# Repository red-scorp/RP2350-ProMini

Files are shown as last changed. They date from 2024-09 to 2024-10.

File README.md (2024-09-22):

```
 ######  ######   #####   #####  #######   ###         ######                #     #            
 #     # #     # #     # #     # #        #   #        #     # #####   ####  ##   ## # #    # # 
 #     # #     #       #       # #       #     #       #     # #    # #    # # # # # # ##   # # 
 ######  ######   #####   #####  ######  #     # ##### ######  #    # #    # #  #  # # # #  # # 
 #   #   #       #             #       # #     #       #       #####  #    # #     # # #  # # # 
 #    #  #       #       #     # #     #  #   #        #       #   #  #    # #     # # #   ## # 
 #     # #       #######  #####   #####    ###         #       #    #  ####  #     # # #    # # 
```

# RP2350-ProMini Project

The RP2350-ProMini project aims to create a replacement for the Arduino Pro Mini using the RP2350 MCU.

## RP2350-ProMini Board

The **RP2350-ProMini** board is a 4-layer board designed to accommodate the popular Raspberry Pi RP2350 MCU in the commonly used, but obsolete, Arduino Pro Mini footprint.

This project is a shoot-off from my earlier [RP2040-ProMini](https://github.com/red-scorp/RP2040-ProMini) project, which was designed to accommodate the Raspberry Pi RP2040 MCU in the same footprint.

Preview:

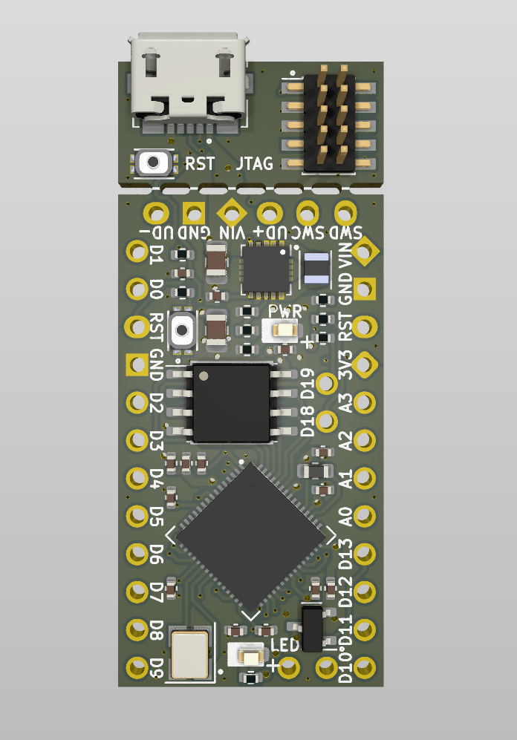
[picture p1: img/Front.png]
RP2350-ProMini Front preview

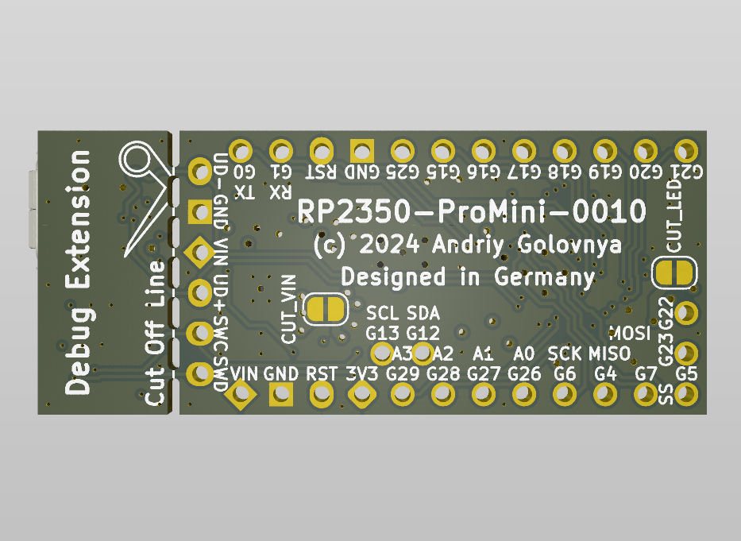
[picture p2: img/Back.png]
RP2350-ProMini Back preview

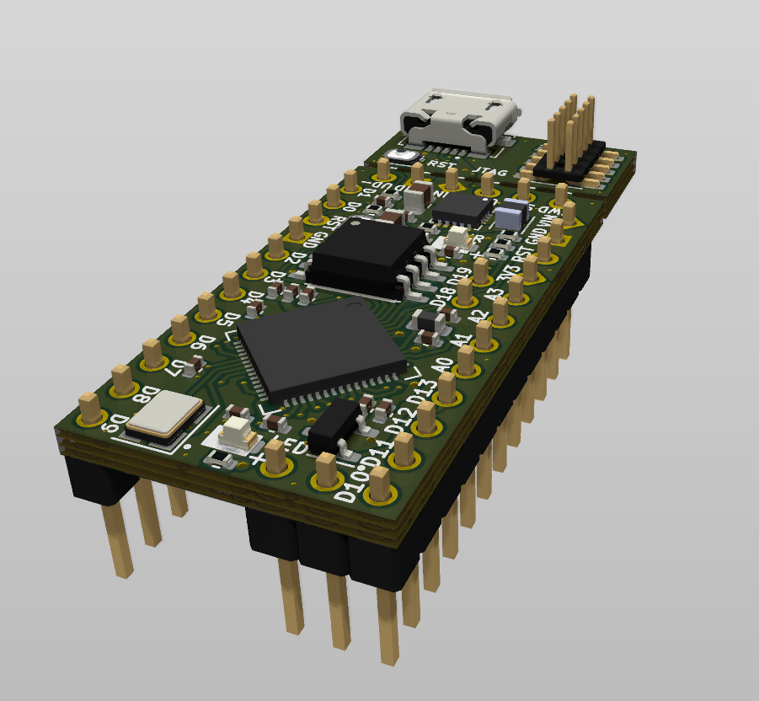
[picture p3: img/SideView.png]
RP2350-ProMini Side View preview


You can view the [Schematics in PDF format](doc/RP2350-ProMini.pdf) for detailed information.

STEP 3D files are available [with pins](doc/RP2350-ProMini-with-pins.step) and [without pins](doc/RP2350-ProMini-board.step).

Features:

- Arduino Pro Mini compatible pinout
- Partially compatible with Arduino Nano RP2040 Connect pinout
- Detachable USB and JTAG extension board with RESET button
- Dual-core Cortex-M33 Raspberry Pi RP2350
- Small footprint suitable for DIY projects
- 21 GPIO pins, including 4 analog inputs
- USB data pins on the side connector
- SWD debugging pins on the side connector
- Buck-Boost converter based 3.3V power supply with input range of 2.5V-12V
- Supports both SOIC and WSON 16MB flash packages
- Flat back side enables use as a sub-assembly
- Two cut points to reduce power consumption of unused components

CAM files, as well as the BOM and CPL files for JLCPCB, are available.

### Board Pinout

Following pinout is used for the board:

| Board Pin | RP2040 Pin | Function | Notes |
| --- | --- | --- | ----- |
| D0 | GPIO1 | UART0 TX | |
| D1 | GPIO0 | UART0 RX | |
| D2 | GPIO25 | | |
| D3 | GPIO15 | | |
| D4 | GPIO16 | | |
| D5 | GPIO17 | | |
| D6 | GPIO18 | | |
| D7 | GPIO19 | | |
| D8 | GPIO20 | | |
| D9 | GPIO21 | | |
| D10 | GPIO5 | SS | |
| D11 | GPIO7 | MOSI | |
| D12 | GPIO4 | MISO | |
| D13 | GPIO6 | SCK | LED |
| D14 A0 | GPIO26 | | |
| D15 A1 | GPIO27 | | |
| D16 A2 | GPIO28 | | |
| D17 A3 | GPIO29 | | |
| D18 | GPIO12 | SDA | |
| D19 | GPIO13 | SCL | |
| D20 | GPIO22 | | |
| D21 | GPIO23 | | |

### Cut Points

There are two cut points on the board to reduce power consumption of unused components.

| Cut Point | Function | Notes |
| --- | --- | ----- |
| CUT_VIN | Separates VIN-to-3V3 power supply with power LED from the rest of the board | This cut point is useful if you want to power the board from 3V3 pin instead of VIN pin. |
| CUT_LED | Separates LED on pin D13 from the rest of the board | This cut point is useful if you want to reduce power consumption of the board. |

## Version History

### v1.0b1 - xx.xx.2024

v1.0b1 board preview

Initial release for testing purposes.

## Links

- [Raspberry Pi RP2350 information page](https://www.raspberrypi.com/documentation/microcontrollers/silicon.html#rp2350).
- [Arduino Pro Mini information page](https://docs.arduino.cc/retired/boards/arduino-pro-mini).
- [Arduino Nano RP2040 Connect page](https://docs.arduino.cc/hardware/nano-rp2040-connect).
- [Arduino SDK for RP2040/RP2350 board](https://github.com/earlephilhower/arduino-pico).

## How to Help

Your contributions as code, resources, or finances are welcome! Please contact me directly via email at andriy.golovnya@gmail.com or through my [GitHub profile](https://github.com/red-scorp).

If you'd like to make a financial contribution, you can donate via [PayPal](http://paypal.me/redscorp) or [Ko-Fi](http://ko-fi.com/redscorp). Your support is greatly appreciated.

Thanks in advance!

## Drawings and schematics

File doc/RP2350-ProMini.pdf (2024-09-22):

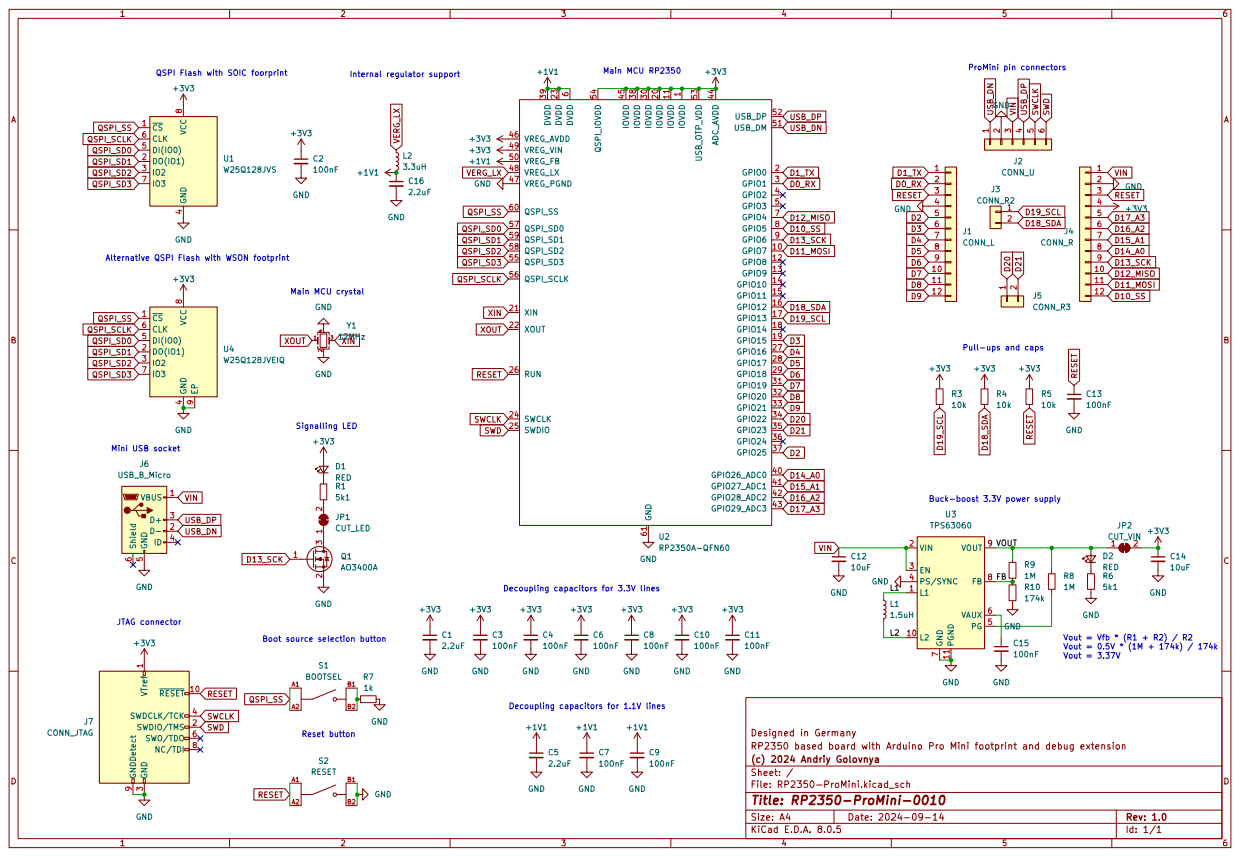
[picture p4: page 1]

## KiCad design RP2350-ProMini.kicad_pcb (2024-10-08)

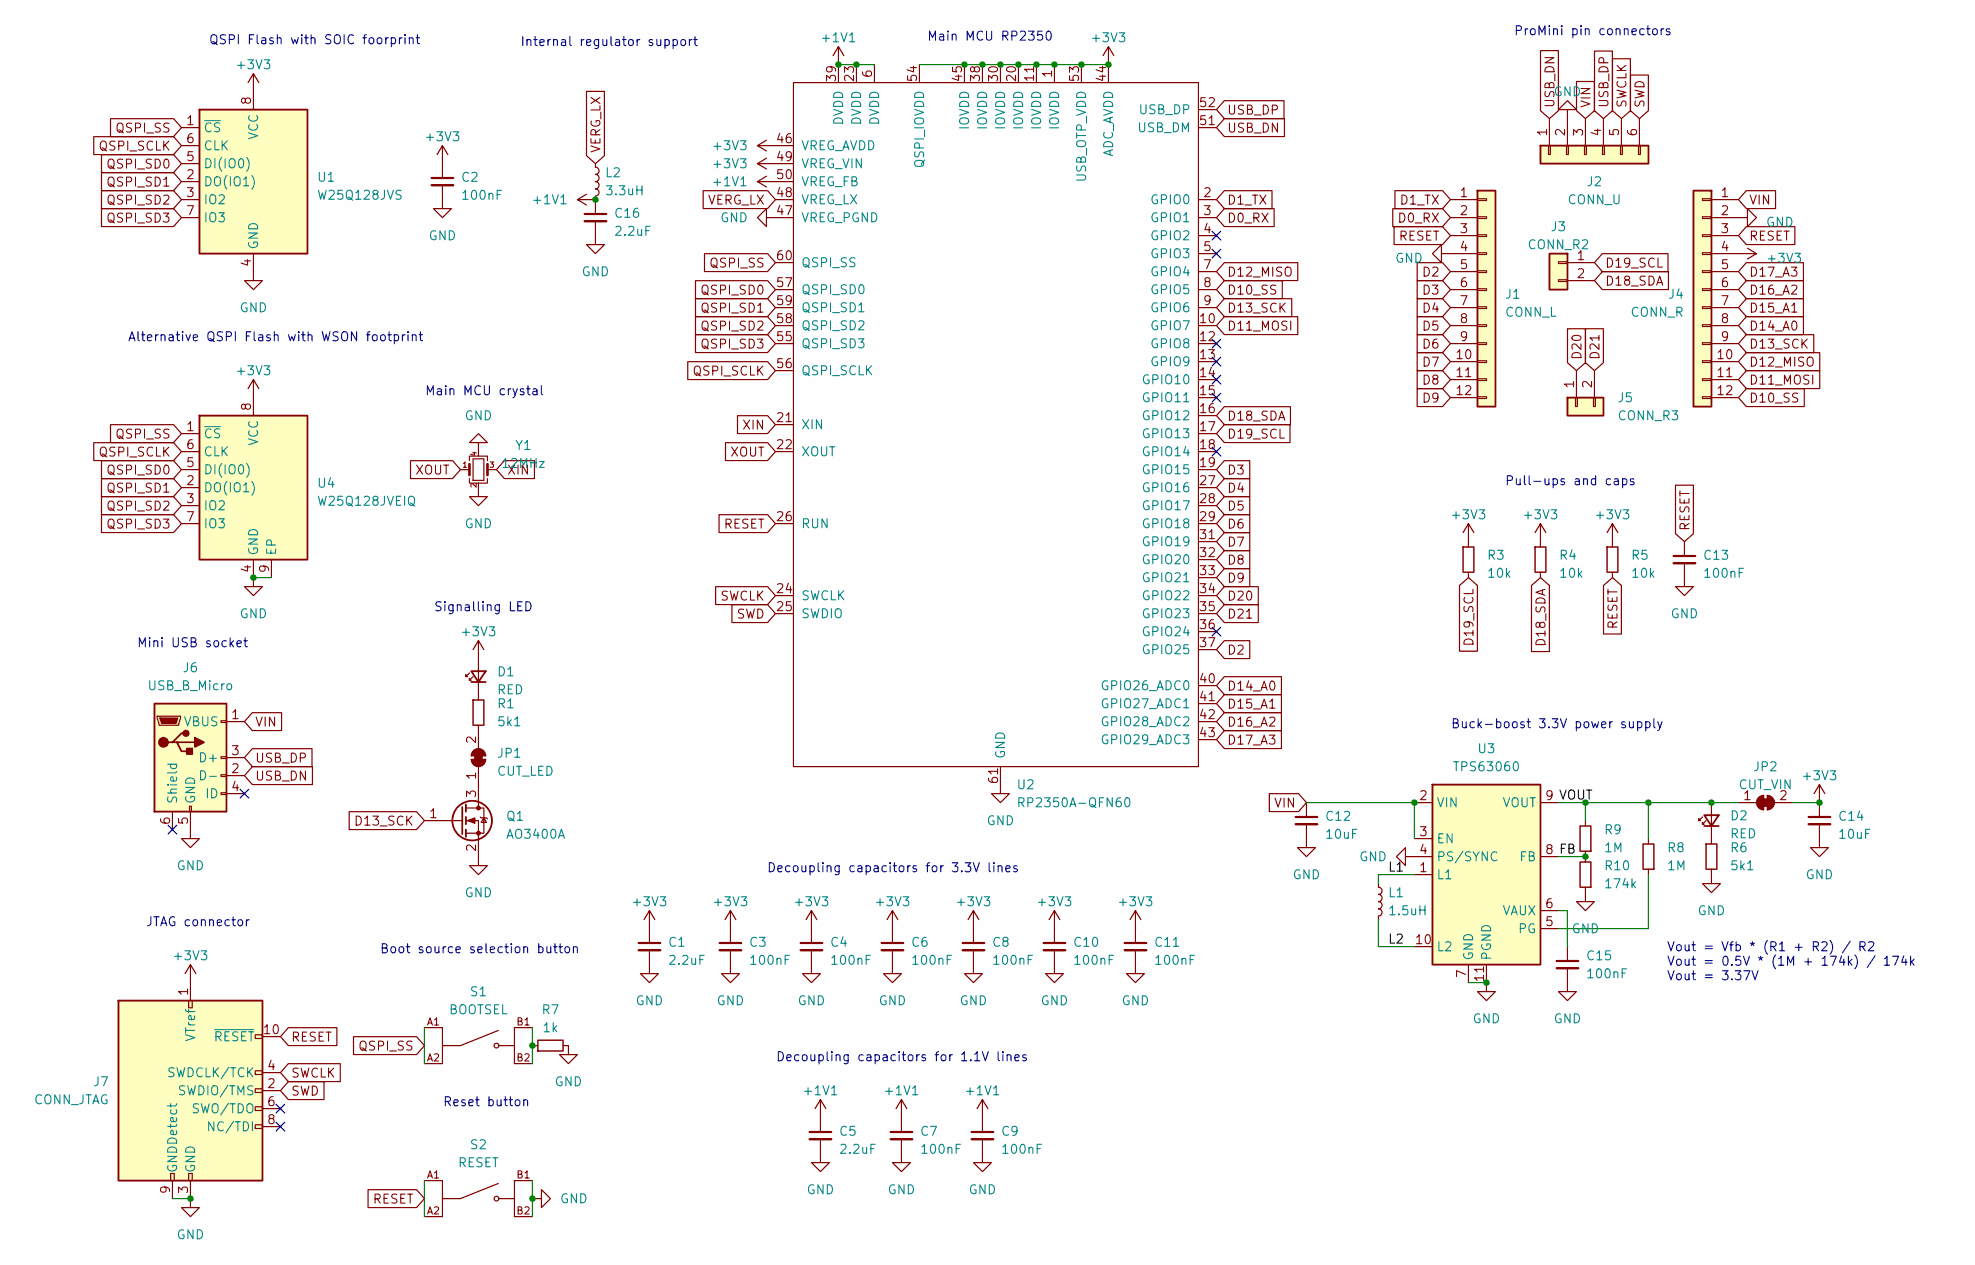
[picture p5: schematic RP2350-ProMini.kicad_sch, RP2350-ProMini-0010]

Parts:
C1, C5, C16: 2.2uF; C_0402_1005Metric
C2, C3, C4, C6, C7, C8, C9, C10, C11, C13, C15: 100nF; C_0402_1005Metric
C12, C14: 10uF; C_0805_2012Metric
D1, D2: RED; LED_0603_1608Metric
J1: CONN_L; PinHeader_1x12_P2.54mm_Vertical
J2: CONN_U; PinHeader_1x06_P2.54mm_Vertical
J3: CONN_R2; PinHeader_1x02_P2.54mm_Vertical
J4: CONN_R; PinHeader_1x12_P2.54mm_Vertical
J5: CONN_R3; PinHeader_1x02_P2.54mm_Vertical
J6: USB_B_Micro; USB_Micro-B_Molex_47346-0001
J7: CONN_JTAG; PinHeader_2x05_P1.27mm_Vertical_SMD
JP1: CUT_LED; SolderJumper-2_P1.3mm_Bridged_RoundedPad1.0x1.5mm
JP2: CUT_VIN; SolderJumper-2_P1.3mm_Bridged_RoundedPad1.0x1.5mm
L1: 1.5uH; L_Murata_DFE201610P
L2: 3.3uH; L_0603_1608Metric
Q1: AO3400A; SOT-23
R1, R6: 5k1; R_0402_1005Metric
R3, R4, R5: 10k; R_0402_1005Metric
R7: 1k; R_0402_1005Metric
R8, R9: 1M; R_0402_1005Metric
R10: 174k; R_0402_1005Metric
S1: BOOTSEL; SW_EVPBB0AAB000; DIGI-KEY_PART_NUMBER P19888CT-ND
S2: RESET; SW_EVPBB0AAB000; DIGI-KEY_PART_NUMBER P19888CT-ND
U1: W25Q128JVS; SOIC-8_5.23x5.23mm_P1.27mm
U2: RP2350A-QFN60; RP2350A_QFN-60_EP_7.75x7.75_Pitch0.4mm
U3: TPS63060; Texas_S-PWSON-N10_ThermalVias
U4: W25Q128JVEIQ; WSON-8-1EP_6x5mm_P1.27mm_EP3.4x4.3mm
Y1: 12MHz; Crystal_SMD_3225-4Pin_3.2x2.5mm

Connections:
+1V1: C5.1, C7.1, C9.1, C16.1, L2.2, U2.6 (DVDD), U2.23 (DVDD), U2.39 (DVDD), U2.50 (VREG_FB)
+3V3: C1.1, C2.1, C3.1, C4.1, C6.1, C8.1, C10.1, C11.1, C14.1, D1.2 (A), J4.4, J7.1 (VTref), JP2.2 (B), R3.1, R4.1, R5.1, U1.8 (VCC), U2.1 (IOVDD), U2.11 (IOVDD), U2.20 (IOVDD), U2.30 (IOVDD), U2.38 (IOVDD), U2.44 (ADC_AVDD), U2.45 (IOVDD), U2.46 (VREG_AVDD), U2.49 (VREG_VIN), U2.53 (USB_OTP_VDD), U2.54 (QSPI_IOVDD), U4.8 (VCC)
/FB: R9.1, R10.2, U3.8 (FB)
/L1: L1.1, U3.1 (L1)
/L2: L1.2, U3.10 (L2)
/VOUT: D2.2 (A), JP2.1 (A), R8.2, R9.2, U3.9 (VOUT)
D0_RX: J1.2, U2.3 (GPIO1)
D1_TX: J1.1, U2.2 (GPIO0)
D2: J1.5, U2.37 (GPIO25)
D3: J1.6, U2.19 (GPIO15)
D4: J1.7, U2.27 (GPIO16)
D5: J1.8, U2.28 (GPIO17)
D6: J1.9, U2.29 (GPIO18)
D7: J1.10, U2.31 (GPIO19)
D8: J1.11, U2.32 (GPIO20)
D9: J1.12, U2.33 (GPIO21)
D10_SS: J4.12, U2.8 (GPIO5)
D11_MOSI: J4.11, U2.10 (GPIO7)
D12_MISO: J4.10, U2.7 (GPIO4)
D13_SCK: J4.9, Q1.1 (G), U2.9 (GPIO6)
D14_A0: J4.8, U2.40 (GPIO26_ADC0)
D15_A1: J4.7, U2.41 (GPIO27_ADC1)
D16_A2: J4.6, U2.42 (GPIO28_ADC2)
D17_A3: J4.5, U2.43 (GPIO29_ADC3)
D18_SDA: J3.2, R4.2, U2.16 (GPIO12)
D19_SCL: J3.1, R3.2, U2.17 (GPIO13)
D20: J5.1, U2.34 (GPIO22)
D21: J5.2, U2.35 (GPIO23)
GND: C1.2, C2.2, C3.2, C4.2, C5.2, C6.2, C7.2, C8.2, C9.2, C10.2, C11.2, C12.2, C13.2, C14.2, C15.2, C16.2, J1.4, J2.2, J4.2, J6.5 (GND), J7.3 (GND), J7.5 (GND), J7.9 (GNDDetect), Q1.2 (S), R6.2, R7.2, R10.1, S2.B1, S2.B2, U1.4 (GND), U2.47 (VREG_PGND), U2.61 (GND), U3.4 (PS/SYNC), U3.7 (GND), U3.11 (PGND), U4.4 (GND), U4.9 (EP), Y1.2, Y1.4
unnamed: D1.1 (K), R1.1
unnamed: D2.1 (K), R6.1
unnamed: JP1.1 (A), Q1.3 (D)
unnamed: JP1.2 (B), R1.2
unnamed: R7.1, S1.B1, S1.B2
unnamed: R8.1, U3.5 (PG)
unnamed: C15.1, U3.6 (VAUX)
QSPI_SCLK: U1.6 (CLK), U2.56 (QSPI_SCLK), U4.6 (CLK)
QSPI_SD0: U1.5 (DI(IO0)), U2.57 (QSPI_SD0), U4.5 (DI(IO0))
QSPI_SD1: U1.2 (DO(IO1)), U2.59 (QSPI_SD1), U4.2 (DO(IO1))
QSPI_SD2: U1.3 (IO2), U2.58 (QSPI_SD2), U4.3 (IO2)
QSPI_SD3: U1.7 (IO3), U2.55 (QSPI_SD3), U4.7 (IO3)
QSPI_SS: S1.A1, S1.A2, U1.1 (~CS), U2.60 (QSPI_SS), U4.1 (~CS)
RESET: C13.1, J1.3, J4.3, J7.10 (~RESET), R5.2, S2.A1, S2.A2, U2.26 (RUN)
SWCLK: J2.5, J7.4 (SWDCLK/TCK), U2.24 (SWCLK)
SWD: J2.6, J7.2 (SWDIO/TMS), U2.25 (SWDIO)
USB_DN: J2.1, J6.2 (D-), U2.51 (USB_DM)
USB_DP: J2.4, J6.3 (D+), U2.52 (USB_DP)
VERG_LX: L2.1, U2.48 (VREG_LX)
VIN: C12.1, J2.3, J4.1, J6.1 (VBUS), U3.2 (VIN), U3.3 (EN)
XIN: U2.21 (XIN), Y1.3
XOUT: U2.22 (XOUT), Y1.1

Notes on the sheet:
Alternative QSPI Flash with WSON footprint
ProMini pin connectors
Main MCU RP2350
Decoupling capacitors for 3.3V lines
Vout = Vfb * (R1 + R2) / R2 Vout = 0.5V * (1M + 174k) / 174k Vout = 3.37V
Main MCU crystal
Decoupling capacitors for 1.1V lines
Pull-ups and caps
Signalling LED
JTAG connector
Reset button
Mini USB socket
Boot source selection button
Buck-boost 3.3V power supply
Internal regulator support
QSPI Flash with SOIC foorprint

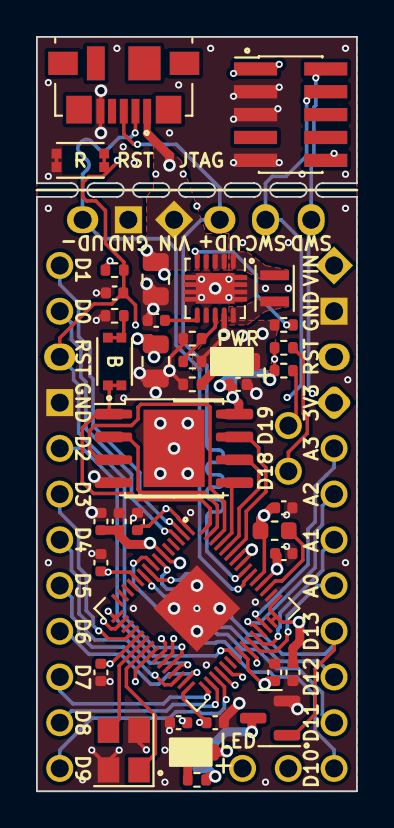
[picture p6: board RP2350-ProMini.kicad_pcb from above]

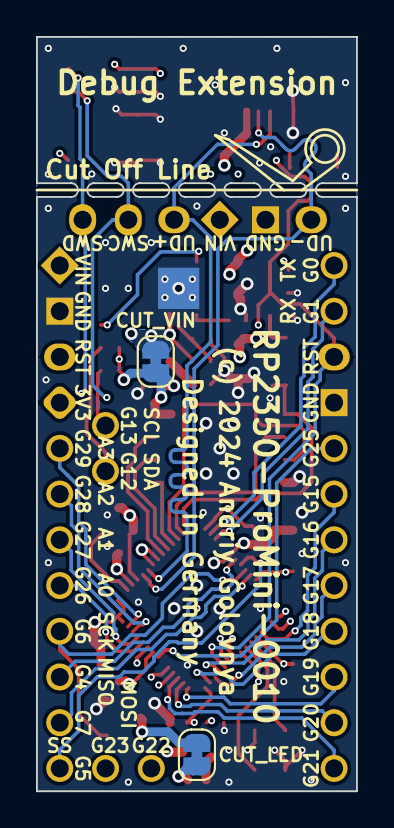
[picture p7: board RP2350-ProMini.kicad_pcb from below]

Board: 4 copper layers, 17.8 x 41.9 mm, 46 parts (7 on the bottom side), 51 nets.

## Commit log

2024-08-31 Initial design based on RP2040-ProMini
    [RP2350-ProMini.kicad_pcb, RP2350-ProMini.kicad_sch]
2024-08-31 Use wrl instead of step 3d model for RP2350
    [RP2350-ProMini.kicad_pcb]
2024-09-01 Added some routing
    [RP2350-ProMini.kicad_pcb, RP2350-ProMini.kicad_sch]
2024-09-03 Moved staff around.
    [RP2350-ProMini.kicad_pcb, RP2350-ProMini.kicad_sch]
2024-09-06 Improved USB data lines
    [RP2350-ProMini.kicad_pcb]
2024-09-22 Generated PDF schematics
2024-09-22 Added generic JLCPCB BOM
    [RP2350-ProMini-20240922-JLCPCB-BOM.xlsx]
2024-09-22 Added generic JLCPCB CPL
    [RP2350-ProMini-20240922-JLCPCB-CPL.xlsx]
2024-10-08 Fixed USB tracers length.
    [RP2350-ProMini.kicad_pcb]
2024-10-08 Generated CAM files
    [RP2350-ProMini-20241008-JLCPCB-BOM.xlsx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]

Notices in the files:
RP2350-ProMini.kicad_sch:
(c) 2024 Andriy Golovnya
